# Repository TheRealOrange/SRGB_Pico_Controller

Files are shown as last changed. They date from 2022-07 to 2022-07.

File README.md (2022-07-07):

# RPi Pico Signal RGB Controller

This is a simple addressable RGB LED controller (WS2812 LEDs) based on the [Raspberry Pi Pico](https://www.raspberrypi.com/products/raspberry-pi-pico/), and compatible with the PC component RGB lighting software known as [Signal RGB](https://www.signalrgb.com/).  This controller features 8 independent addressable RGB LED outputs, each with filtering capacitors and a resistor on the data line per the recommended specifications. Each LED channel is also driven by the Pico through a level-shifter, providing full 5V to the data line. To supply 5V to the controller, there are two pads where the user can choose to solder a Molex, SATA power, or other 5V power source.

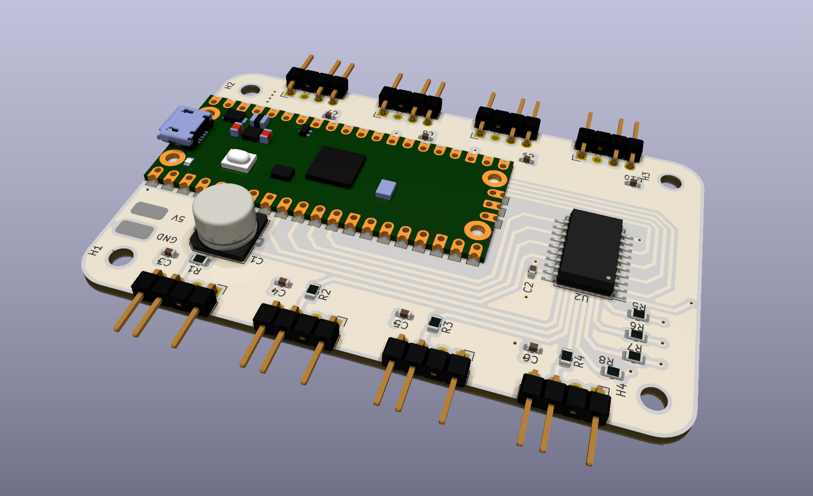
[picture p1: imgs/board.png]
Controller Board Image


In case anyone wants to use this design, the KiCAD project files are in the folder `srgb_pico`, and the symbol fields list both LCSC and DigiKey part numbers.

The number of LEDs on each channel is configurable via the online configurator available at [SRGBmods](https://srgbmods.net/). The controller made possible by, and relies on the code provided by [SRGBmods](https://srgbmods.net/). I am not the author of the code which is meant to run on this controller.

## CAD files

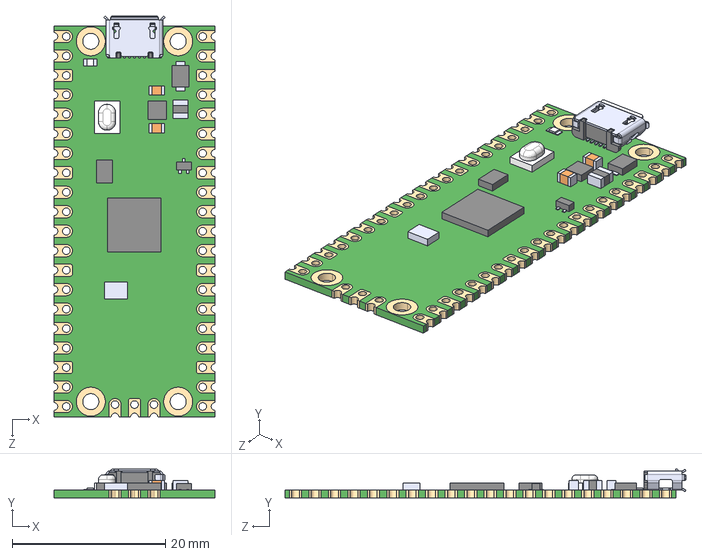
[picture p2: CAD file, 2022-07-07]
srgb_pico/3d/SC0915.step
21.0 x 3.73 x 52.3 mm

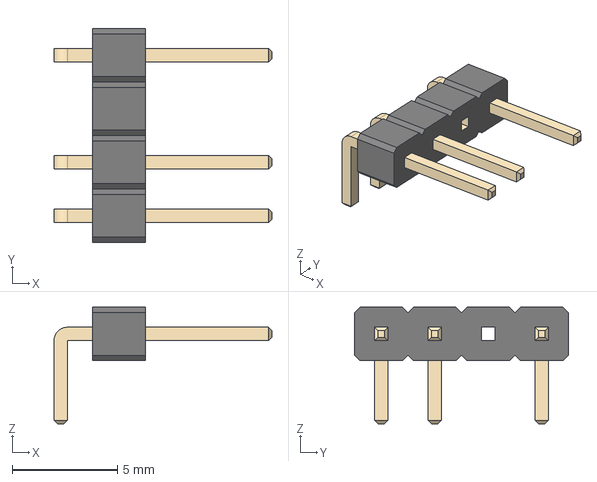
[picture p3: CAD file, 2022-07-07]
srgb_pico/3d/PinHeader_ARGB_1x04_P2.step
10.4 x 10.2 x 5.54 mm

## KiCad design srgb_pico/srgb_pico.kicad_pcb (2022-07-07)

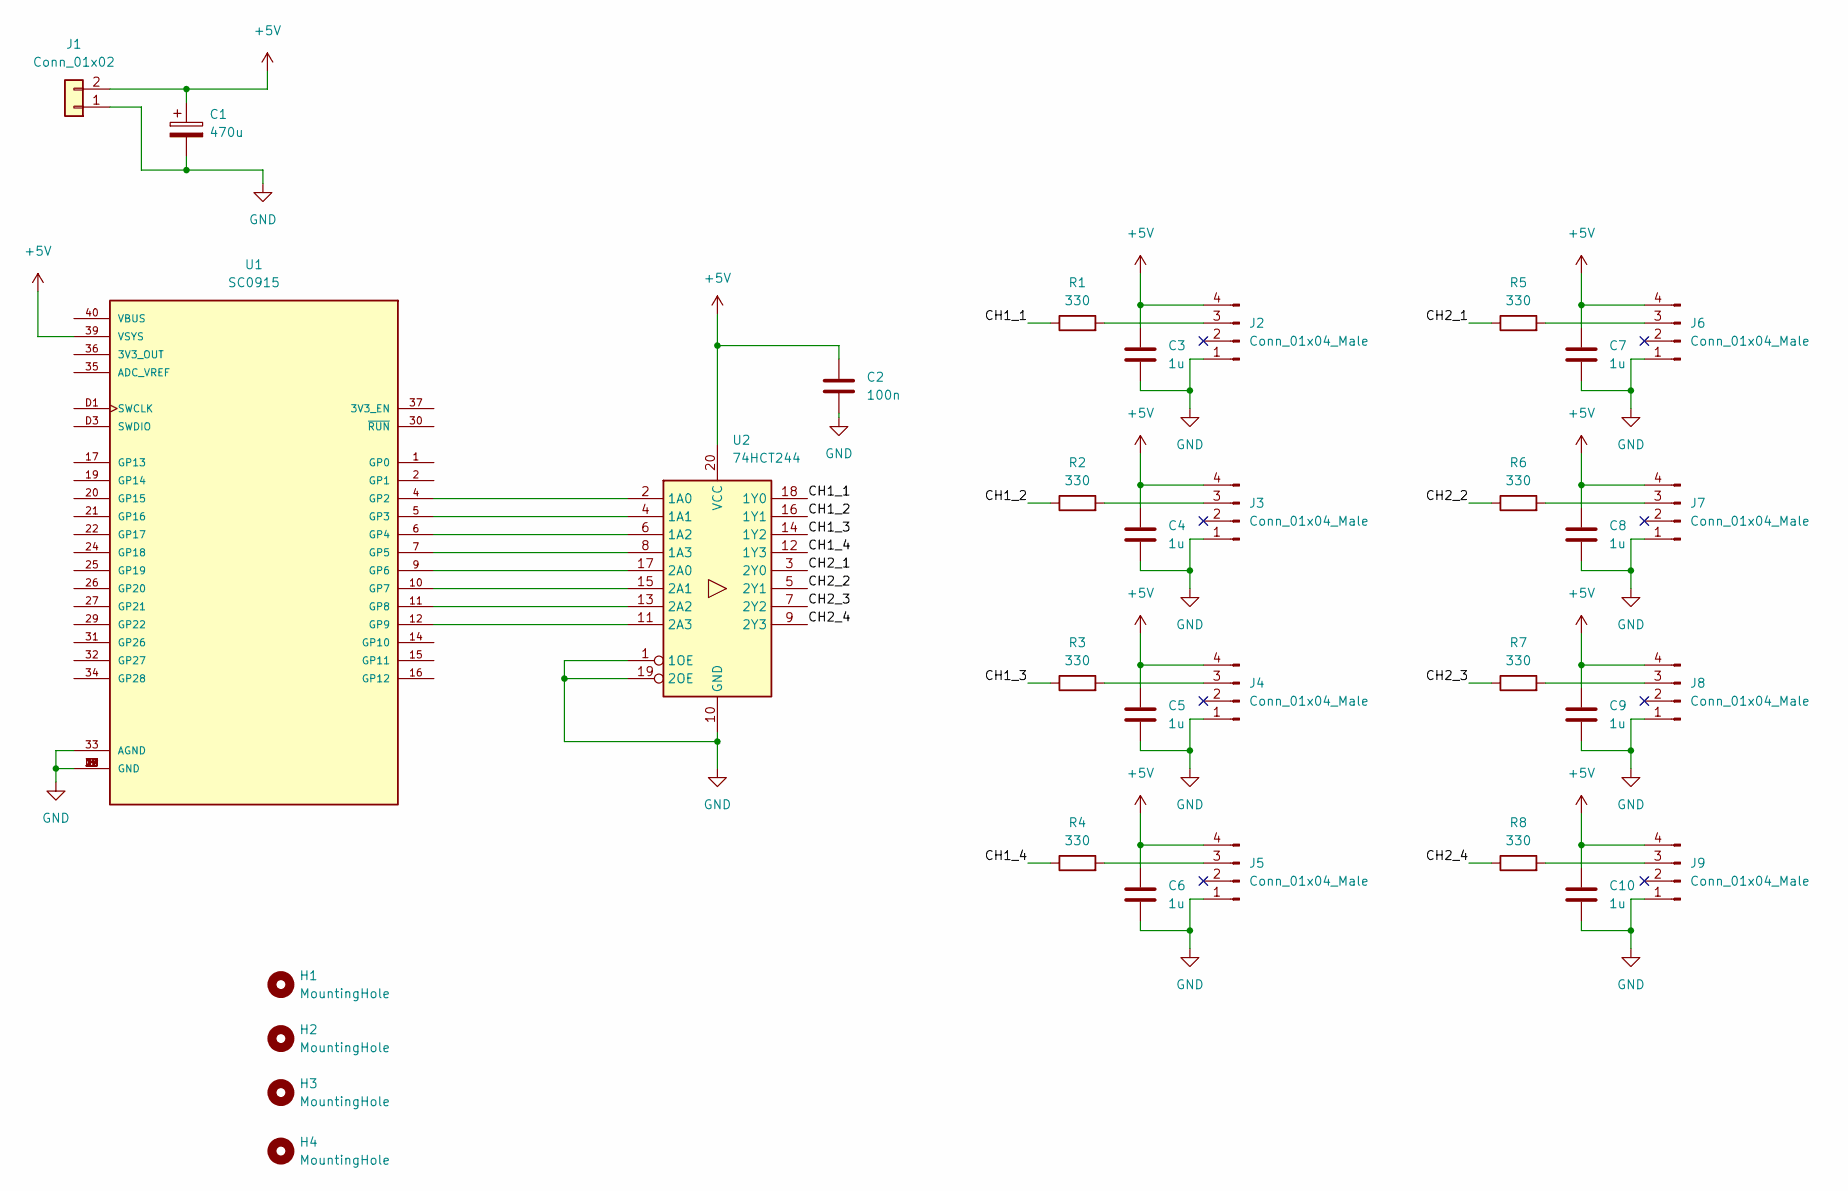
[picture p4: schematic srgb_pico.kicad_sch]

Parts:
C1: 470u; C_Elec_8x6.2; digikey_part_num 732-6451-1-ND
C2: 100n; C_0603_1608Metric; digikey_part_num 1276-1935-1-ND
C3, C4, C5, C6, C7, C8, C9, C10: 1u; C_0603_1608Metric; digikey_part_num 1276-1102-1-ND
H1, H2, H3, H4: MountingHole; MountingHole_3.2mm_M3_DIN965
J1: Conn_01x02; pwr_in
J2, J3, J4, J5, J6, J7, J8, J9: Conn_01x04_Male; PinHeader_ARGB_1x04_P2.54mm_Horizontal; digikey_part_num ED8564-04-ND
R1, R2, R3, R4, R5, R6, R7, R8: 330; R_0805_2012Metric; digikey_part_num A130131CT-ND
U1: SC0915; MODULE_SC0915; digikey_part_num 2648-SC0915CT-ND
U2: 74HCT244; SOIC-20W_7.5x12.8mm_P1.27mm; digikey_part_num 74HCT244DCT-ND

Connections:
+5V: C1.1, C2.2, C3.1, C4.1, C5.1, C6.1, C7.1, C8.1, C9.1, C10.1, J1.2, J2.4, J3.4, J4.4, J5.4, J6.4, J7.4, J8.4, J9.4, U1.39 (VSYS), U2.20 (VCC)
/CH1_1: R1.1, U2.18 (1Y0)
/CH1_2: R2.1, U2.16 (1Y1)
/CH1_3: R3.1, U2.14 (1Y2)
/CH1_4: R4.1, U2.12 (1Y3)
/CH2_1: R5.1, U2.3 (2Y0)
/CH2_2: R6.1, U2.5 (2Y1)
/CH2_3: R7.1, U2.7 (2Y2)
/CH2_4: R8.1, U2.9 (2Y3)
GND: C1.2, C2.1, C3.2, C4.2, C5.2, C6.2, C7.2, C8.2, C9.2, C10.2, J1.1, J2.1, J3.1, J4.1, J5.1, J6.1, J7.1, J8.1, J9.1, U1.3 (GND), U1.8 (GND), U1.13 (GND), U1.18 (GND), U1.23 (GND), U1.28 (GND), U1.33 (AGND), U1.38 (GND), U1.D2 (GND), U2.1 (1OE), U2.10 (GND), U2.19 (2OE)
unnamed: J2.3, R1.2
unnamed: J3.3, R2.2
unnamed: J4.3, R3.2
unnamed: J5.3, R4.2
unnamed: J6.3, R5.2
unnamed: J7.3, R6.2
unnamed: J8.3, R7.2
unnamed: J9.3, R8.2
unnamed: U1.4 (GP2), U2.2 (1A0)
unnamed: U1.5 (GP3), U2.4 (1A1)
unnamed: U1.6 (GP4), U2.6 (1A2)
unnamed: U1.7 (GP5), U2.8 (1A3)
unnamed: U1.9 (GP6), U2.17 (2A0)
unnamed: U1.10 (GP7), U2.15 (2A1)
unnamed: U1.11 (GP8), U2.13 (2A2)
unnamed: U1.12 (GP9), U2.11 (2A3)

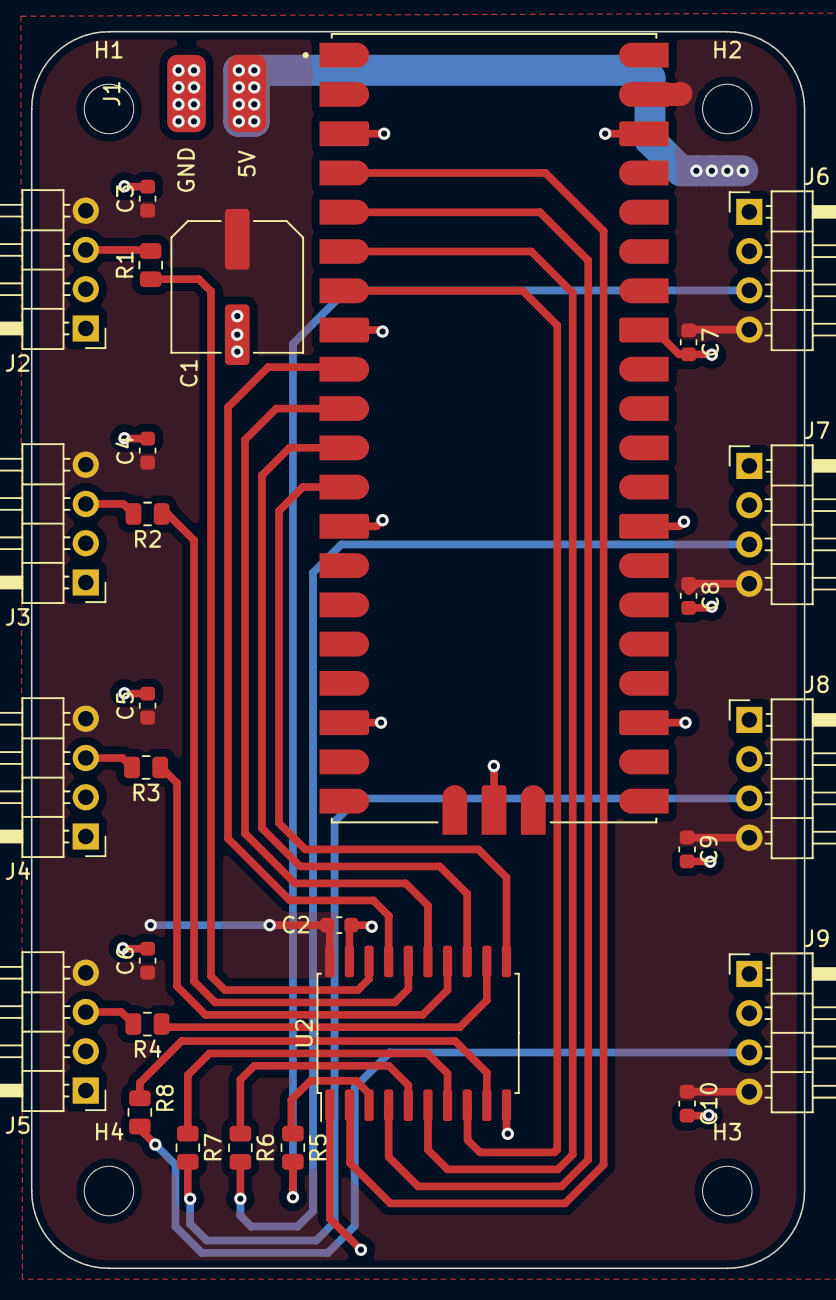
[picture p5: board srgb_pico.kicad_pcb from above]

Board: 2 copper layers, 50.0 x 80.0 mm, 33 parts (0 on the bottom side), 26 nets.

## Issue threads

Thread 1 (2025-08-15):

tried following the tutorial rgb devices dont light up

Grumbo-pc, 2025-08-15:
for context i am trying to make an rgb hub so i can use it with signal rgb i stumbled upon this and i was like great i ordered a pi pico and some jumper wires incase i need any, programing the pi was super wasy but ive programed it to give an output from GP3 and when i connect up anything it just doesnt output anything and if you suspect its a posative, negative wire issuse ive tried reversing the terminals in case i was an idiot and i only got a windows power surge warning here is how the pinouts to my setup worked

usb port 1 -> usb cable -> pi pico
pico GP3 port -> data header on a 3 pin rgb splitter i had (i tried it without the splitter no difference)
usb port 2 -> usb cable -> ground and +5v cales to the corresponding cables for the rgb devices

my devices are a deepcool fan and some generic branded nvme heatsink with rgb

any kind of help you would be able to provide would be great, thanks
